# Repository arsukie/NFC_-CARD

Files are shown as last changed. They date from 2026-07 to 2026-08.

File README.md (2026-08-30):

# NFC Hacker Card 
This is  Design of my NFC Bussiness Card or You can call it a Hacker Card as well. I was starting out the Hardware and found this thing as a cool project and Let me know the basics so I build this Thing.

### Project function
This is a NFC card mean it can read and write the NFC commands and exectue them as well. It uses NT3H2111W0FHKH IC for the NFC handeling and a 25x48 antenna , a LED light , a 47Ω Resistor and 220nF Capacitor. The led Will blink whenever the antenna harvests the energy.

# NFC Business Card - Bill of Materials
 
An NFC-powered business card. The NT3H2111W0FHKH handles NFC communication and harvests energy from the phone to light up an LED — no battery needed. The antenna is engraved directly on the PCB.
 
## Components
 
- **NT3H2111W0FHKH** - NFC chip, the main component of the card. Handles NFC functionality and harvests energy from the phone to light up the LED.
- **~2V LED** - using C2296 (also known as 17-21SUYC/TR8), but any similar 2V LED works.
- **47Ω resistor**
- **220nF capacitor**
- **NFC antenna** - engraved on the PCB itself, no separate part needed.
- 
## Bill of Materials
 
| No. | Quantity | Comment | Designator | Footprint | Value | Manufacturer Part | Manufacturer | Supplier Part | Supplier |
|---|---|---|---|---|---|---|---|---|---|
| 1 | 1 | 220nF | C1 | C0603 | | CL10B224KA8NNNC | SAMSUNG | C21120 | [LCSC](https://www.lcsc.com/product-detail/C21120.html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) |
| 2 | 1 | 17-21SUYC/TR8 | LED1 | LED0805-R-RD | | KT-0805 Yellow LED | KENTO | C2296 | [LCSC](https://www.lcsc.com/product-detail/C2296.html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) |
| 3 | 1 | 47Ω | R1 | R0603 | | 0603WAF470JT5E | UNI-ROYAL | C23182 | [LCSC](https://www.lcsc.com/product-detail/C23182.html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) |
| 4 | 1 | NT3H2111W0FHKH | U1 | XQFN-8_L1.6-W1.6-P0.50-BL_NT3H2111W0FHKH | | NT3H2111W0FHKH | NXP | C710403 | [LCSC](https://www.lcsc.com/product-detail/C710403.html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) |
 
## PCB & Shipping
 
| Type | Item | Description | Qty | Build Time | Price |
|---|---|---|---|---|---|
| PCB | Gerber_Bussiness_card_Y9 | PCB prototype: Y9-13163216A, Black, 1.6 Thickness, HASL(with lead) | 5 pcs | 24 hours | $4.00 |
| PCBA | Gerber_Bussiness_card_Y9 | Economic PCBA: SMT026082762821-13163216A, Assemble top side | 2 pcs | 1 - 2 days | $15.78 |
 
| | |
|---|---|
| **PCB (Merchandise)** | $19.78 |
| Shipping | $16.01 |
| **Subtotal** | **$35.79** |
## Cart




### NOTE 

THE NFC ANTENNA USED IN THE SCHEMATIC IS FROM THE USER CONTRIBUTED LIBRARY FROM THE EASYEDA SO YOU MIGHT NEED TO GET THE PCB OR YOU CAN USE ANY ANTENNA THAT WORKS FOR NFC AND SUPPORTS NT3H2111W0FHKH IC. I AM USING A 25X48 FOOTPRINT AND IT IS ENGRAVED ON THE COPPER LAYER OF THE PCB.

# Schematics
Schematic_Business-Card_2026-07-28

# Boardview
PCB_PCB_Business-Card_2026-07-28

# 3D View 



### Author - Arsukie

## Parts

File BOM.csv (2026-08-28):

Selected Parts (4 items)
Part Detail | Selected by | Top Designator | Qty | Source | Ext. Price
NT3H2111W0FHKH (Extended, C710403) | System | U1 | 2 | JLCPCB | 1.2538
CL10B224KA8NNNC (Basic, C21120) | System | C1 | 2 | JLCPCB | 0.0336
0603WAF470JT5E (Basic, C23182) | System | R1 | 2 | JLCPCB | 0.0086
KT-0805Y (Basic, C2296) | System | LED1 | 2 | JLCPCB | 0.0306
PCB & Shipping
Type | Item | Description | Qty | Build Time | Price
PCB | Gerber_Bussiness_card_Y9 | PCB prototype: Y9-13163216A | 5 pcs | 24 hours | 4
PCBA | Gerber_Bussiness_card_Y9 | Economic PCBA: SMT026082762821-13163216A | 2 pcs | 1 - 2 days | 15.78
PCB (Merchandise) | 19.78
Shipping | 16.01
Subtotal | 35.79

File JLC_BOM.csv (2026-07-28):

No. | Quantity | Comment | Designator | Footprint | Value | Manufacturer Part | Manufacturer | Supplier Part | Supplier
1 | 1 | 25X48MM_NFC_ANTENNA | 1 | 25X48MM_NFC_ANTENNA
2 | 1 | 220nF | C1 | C0603 |  | CL10B224KA8NNNC | SAMSUNG(ä¸‰æ˜Ÿ) | C21120 | LCSC
3 | 1 | 17-21SUYC/TR8 | LED1 | LED0805-R-RD |  | KT-0805é»„ç ¯ | KENTO | C2296 | LCSC
4 | 1 | 47Î- | R1 | R0603 |  | 0603WAF470JT5E | UNI-ROYAL(åŽšå£°) | C23182 | LCSC
5 | 1 | NT3H2111W0FHKH | U1 | XQFN-8_L1.6-W1.6-P0.50-BL_NT3H2111W0FHKH |  | NT3H2111W0FHKH | NXP(æ -æ-ºæµ¦) | C710403 | LCSC

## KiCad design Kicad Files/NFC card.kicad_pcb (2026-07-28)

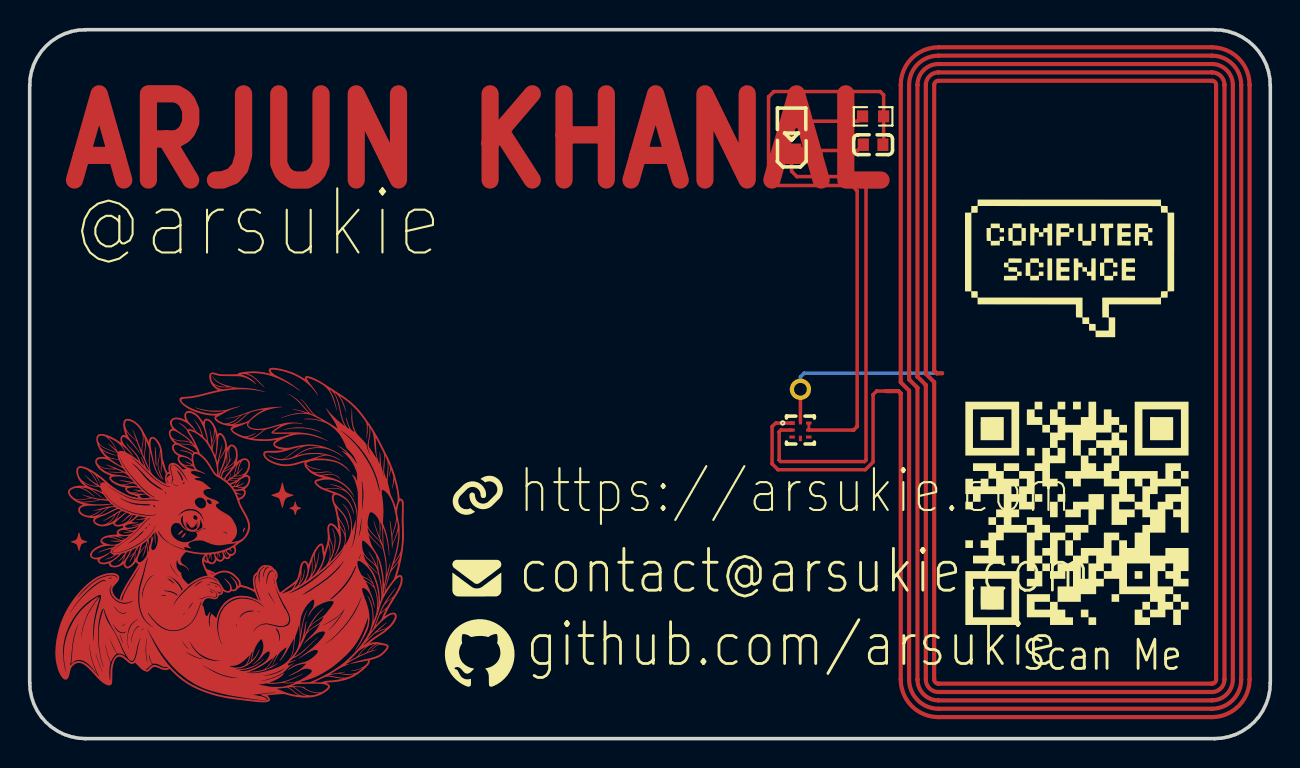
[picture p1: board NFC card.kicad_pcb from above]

Board: 2 copper layers, 88.9 x 50.8 mm, 5 parts (0 on the bottom side), 5 nets.

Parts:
1: 25X48MM_NFC_ANTENNA
C1: C0603
LED1: LED0805-R-RD
R1: R0603
U1: XQFN-8_L1.6-W1.6-P0.50-BL_NT3H2111W0FHKH

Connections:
R1_1: LED1.1, R1.1
U1_1: 1.P$1, U1.1
U1_2: C1.1, LED1.2, U1.2
U1_6: C1.2, R1.2, U1.6, U1.7
U1_8: 1.P$2, U1.8

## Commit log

2026-07-28 Project Upload
    [NFC card.kicad_pcb, NFC card.kicad_sch]
2026-07-28 Kicad Files Seperation
    [NFC card.kicad_pcb, NFC card.kicad_sch]
2026-07-28 Files Uploaded For the PCB
    [BOM_Bussiness_card.csv, Pick_Place_Bussiness_card.csv]
2026-07-28 BOM Update
2026-08-08 Update README with additional image and NFC notes
    Added a new image to the README and provided notes on the NFC antenna used in the schematic.
2026-08-28 Updated BOM file from .csv to .xlsx and included required fields
    [BOM.csv, BOM.xlsx]
2026-08-28 Updated BOM
    [BOM.csv, BOM.xlsx]
2026-08-28 JLC BOM Update for Direct ordering realibility
    [JLC_BOM.csv]
